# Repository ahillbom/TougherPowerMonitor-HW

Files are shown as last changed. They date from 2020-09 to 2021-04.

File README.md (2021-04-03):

### What is this?

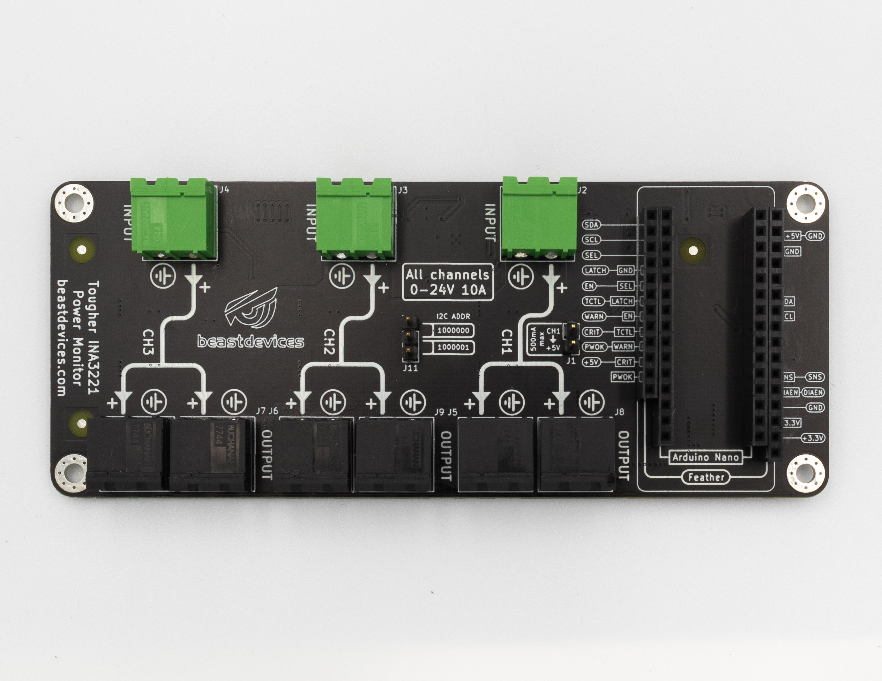
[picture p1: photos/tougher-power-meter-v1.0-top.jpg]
Tougher INA3221 power meter 3D side view. Assembled Tougher Power Meter Top View


Power monitor with three channels, each capable of continuous 10A and 24V. It is compatible with both Arduino and Feather, and is based on a popular INA3221. The power monitor is more robust compared to other modules based on this IC. Each channel has proper RC filtering with TVS diodes to prevent INA3221 from being destroyed by transients, and to eliminate glitches. Pluggable screw terminals are rated for 15A, and can handle 12 to 30 AWG wires.

The third channel has a TPS1HB08A power switch, to be able to disconnect the load.
The board can also provide power to the Feather or Arduino from the first channel via a built-in buck converter.

### Block diagram

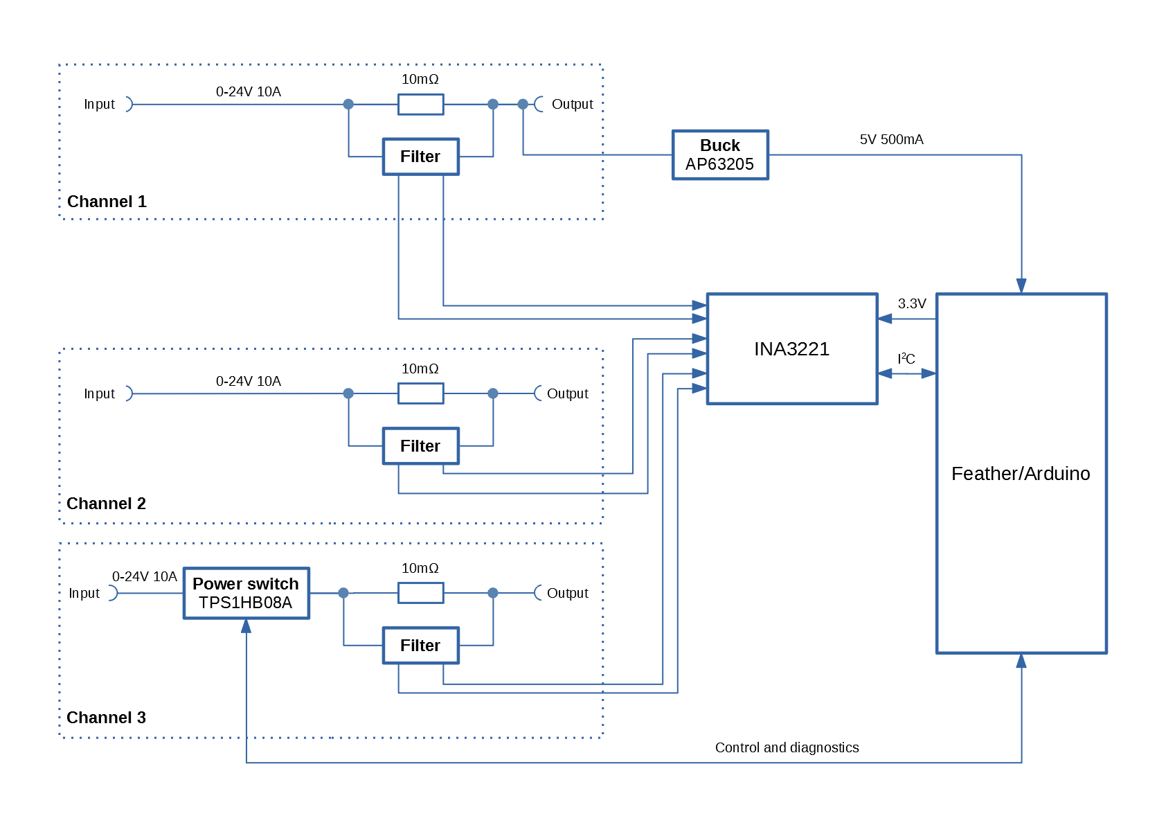
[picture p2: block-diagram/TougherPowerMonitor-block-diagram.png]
Tougher INA3221 Power Meter Block Diagram block diagram


### Schematics

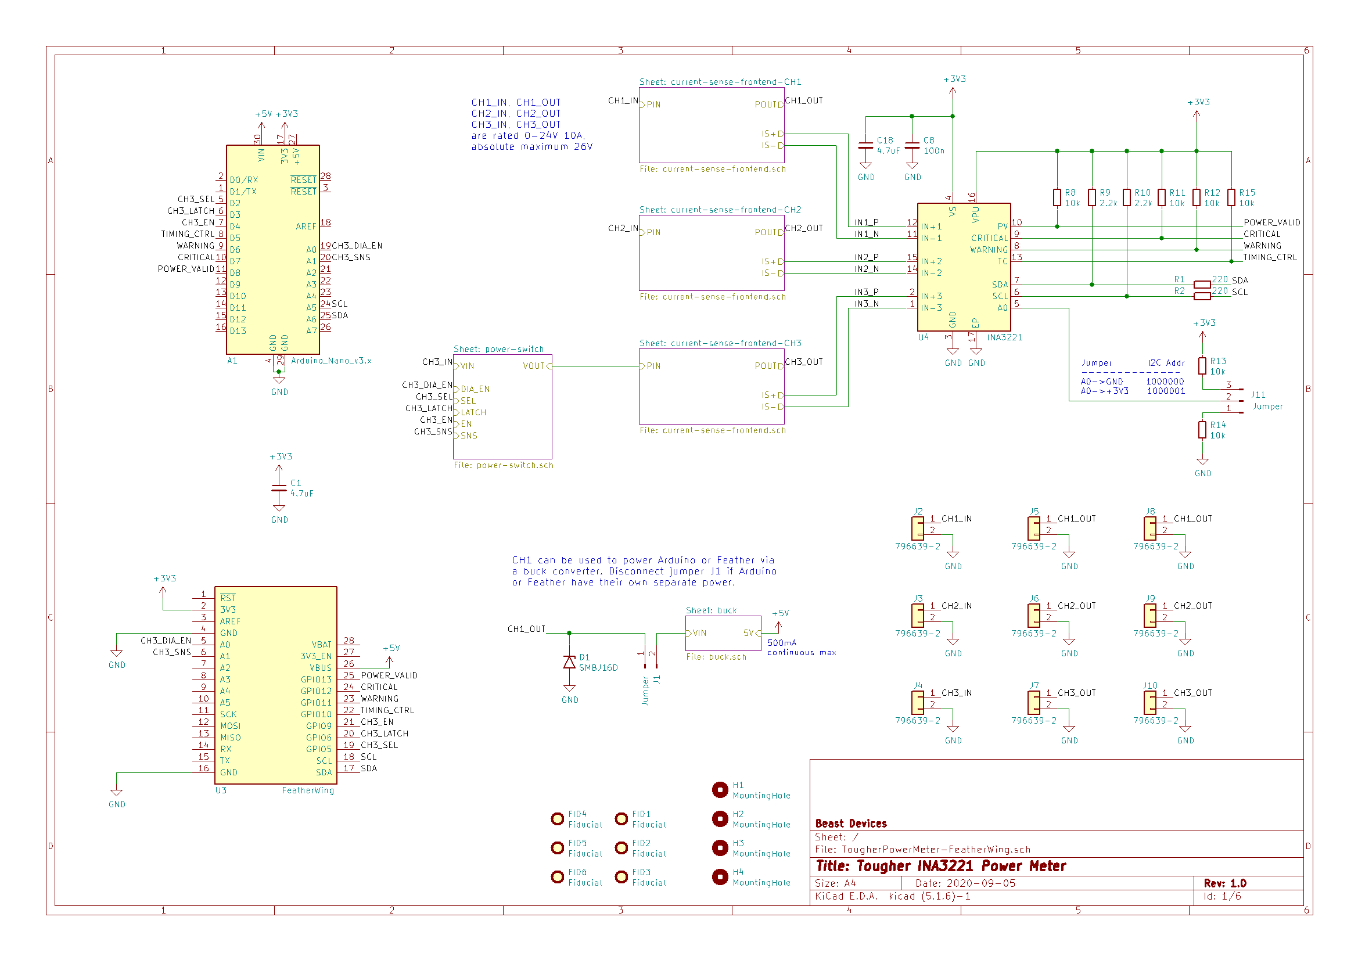
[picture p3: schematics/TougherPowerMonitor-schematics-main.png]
Tougher INA3221 Power Meter Schematics schematics


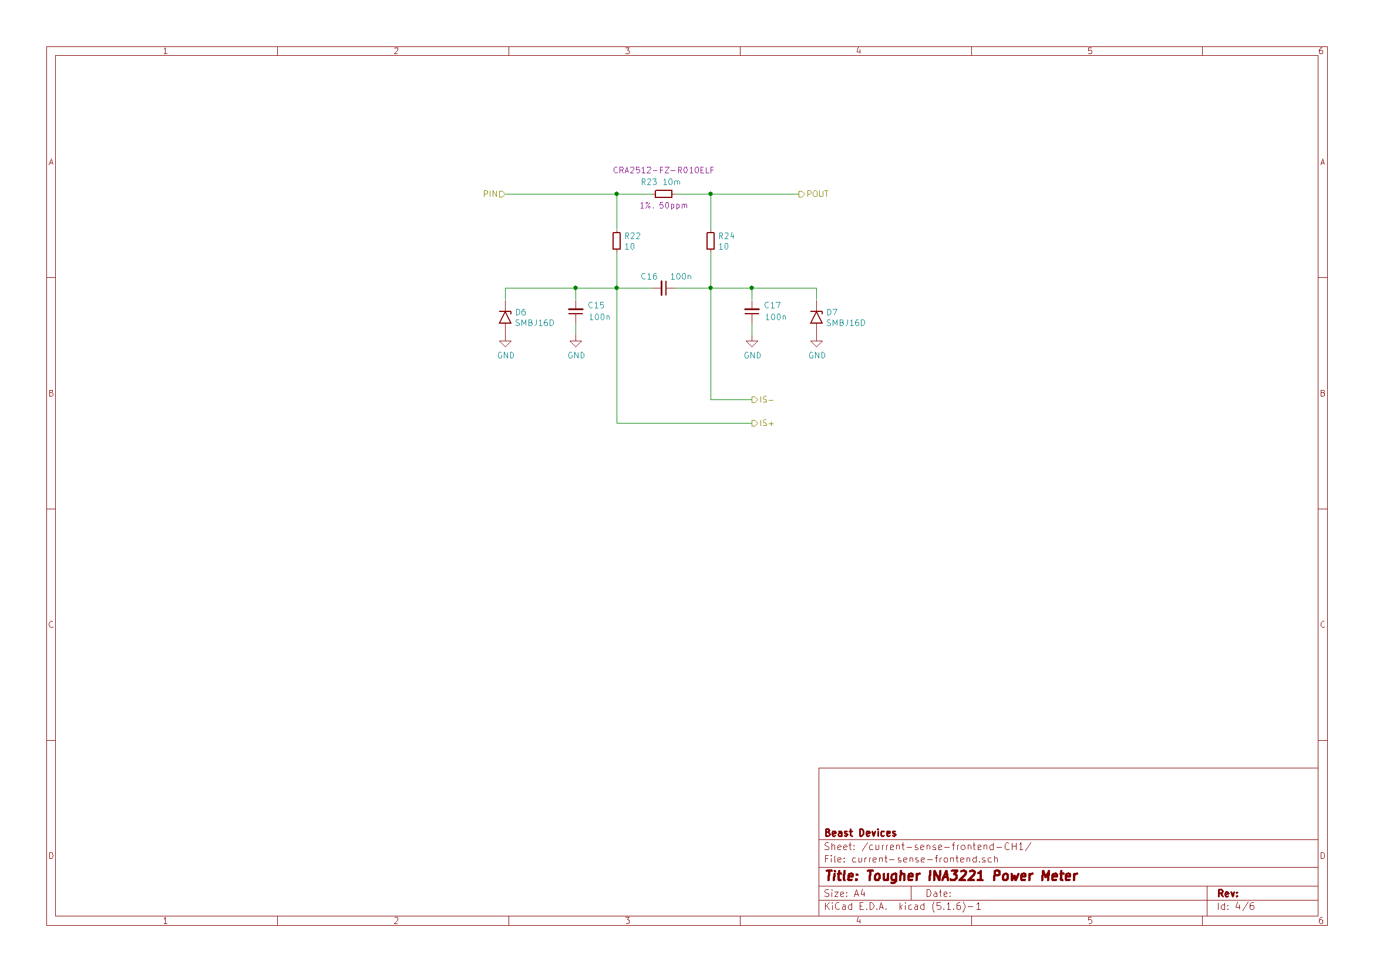
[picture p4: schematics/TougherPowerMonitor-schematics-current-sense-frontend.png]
Current sense resistor with RC filtering and TVS diodes. schematics


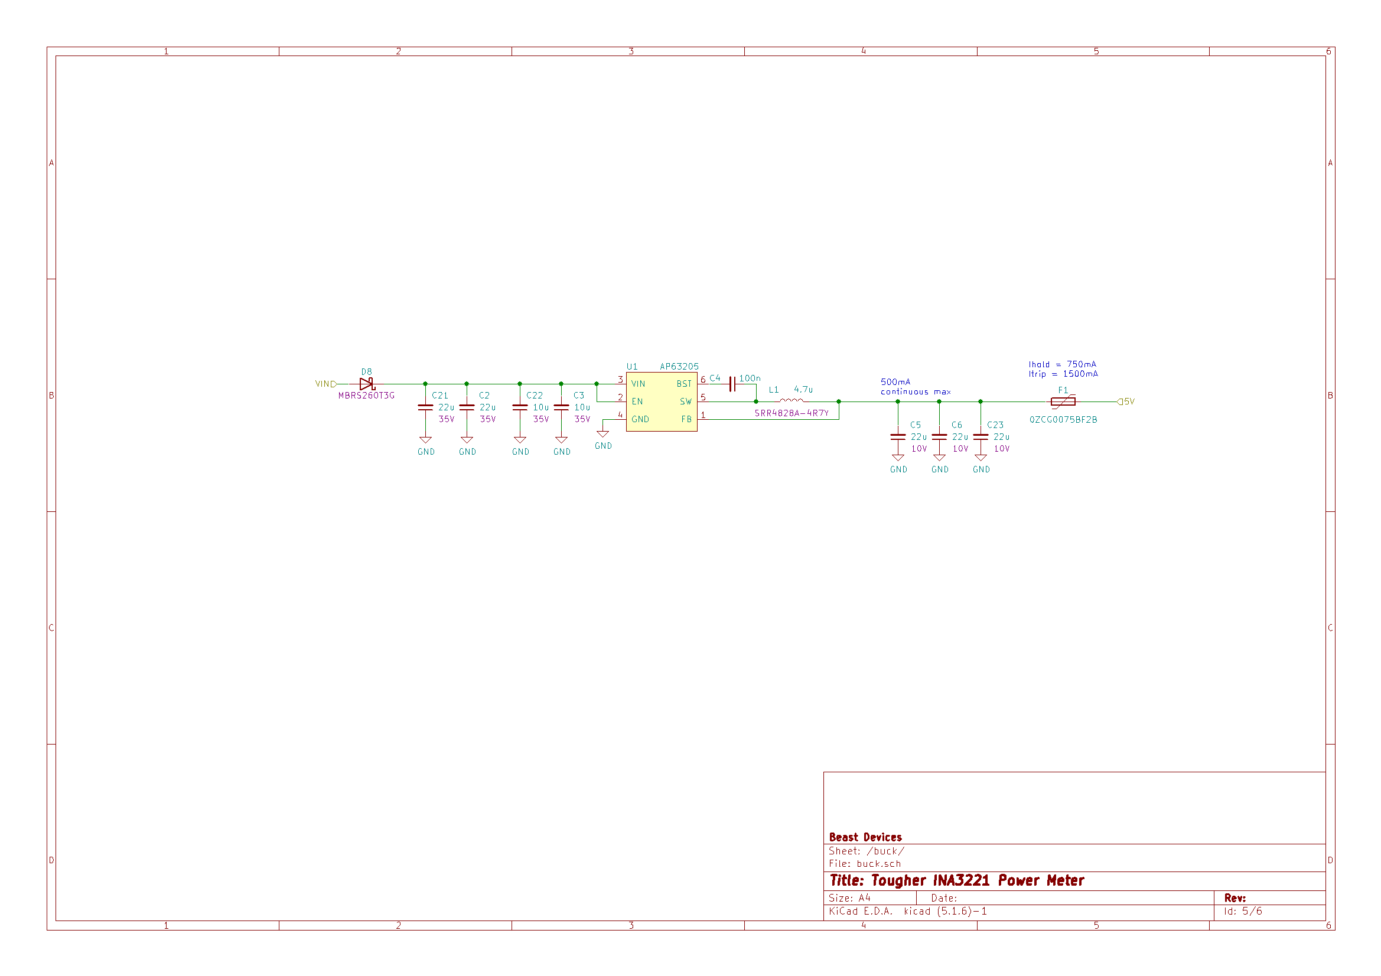
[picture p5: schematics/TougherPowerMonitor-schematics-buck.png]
Schematics of AP63205 buck converter. schematics


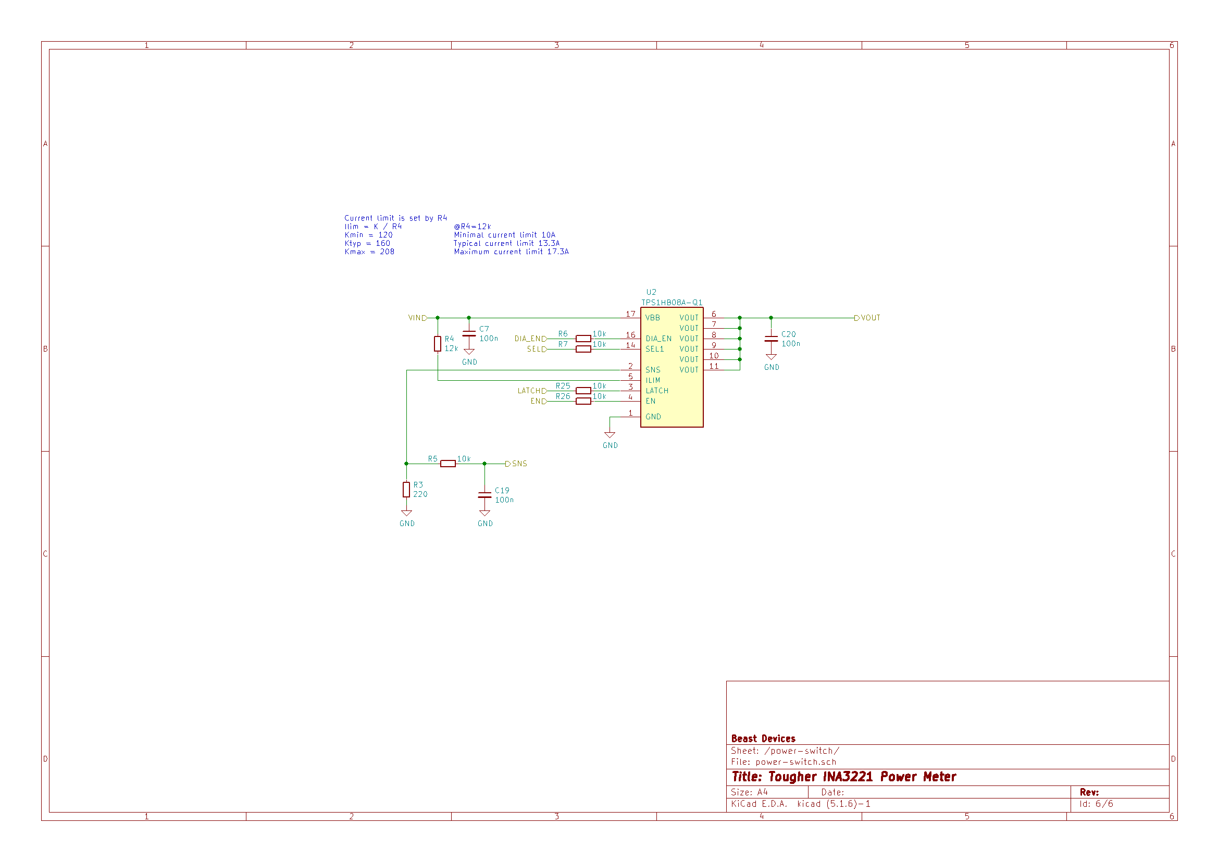
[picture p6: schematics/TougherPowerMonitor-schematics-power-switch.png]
Schematics of TPS1HB08 high-side power switch. schematics


### Assembled board

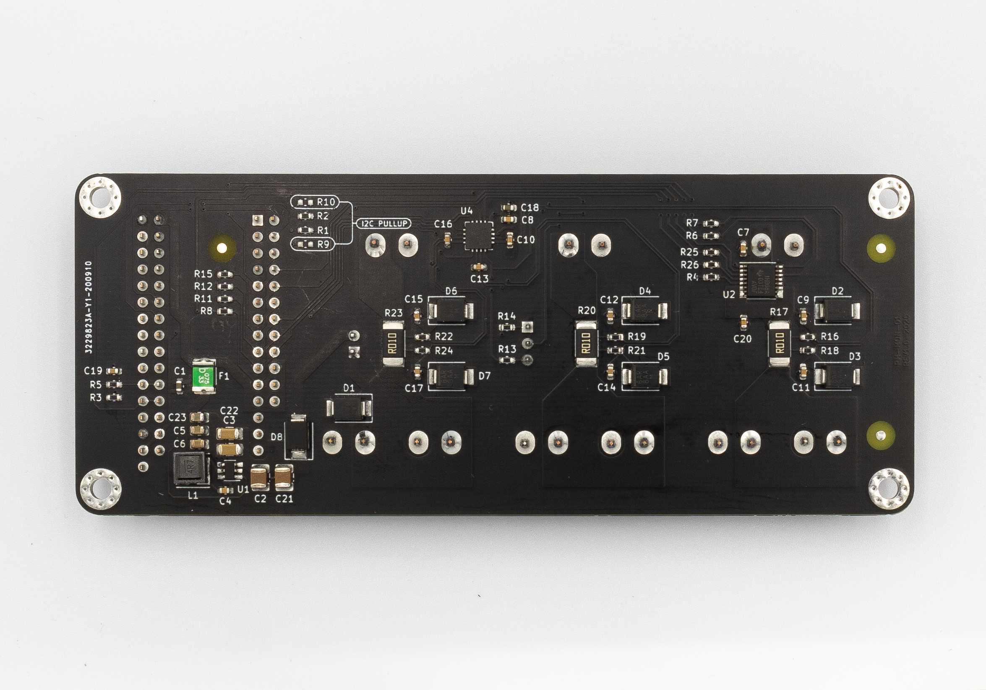
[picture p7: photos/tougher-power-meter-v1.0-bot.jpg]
Assebmbled Tougher Power Meter (bottom view). Assembled Tougher Power Meter Bottom View

Assebmbled Tougher Power Meter (side view). Assembled Tougher Power Meter Side View View

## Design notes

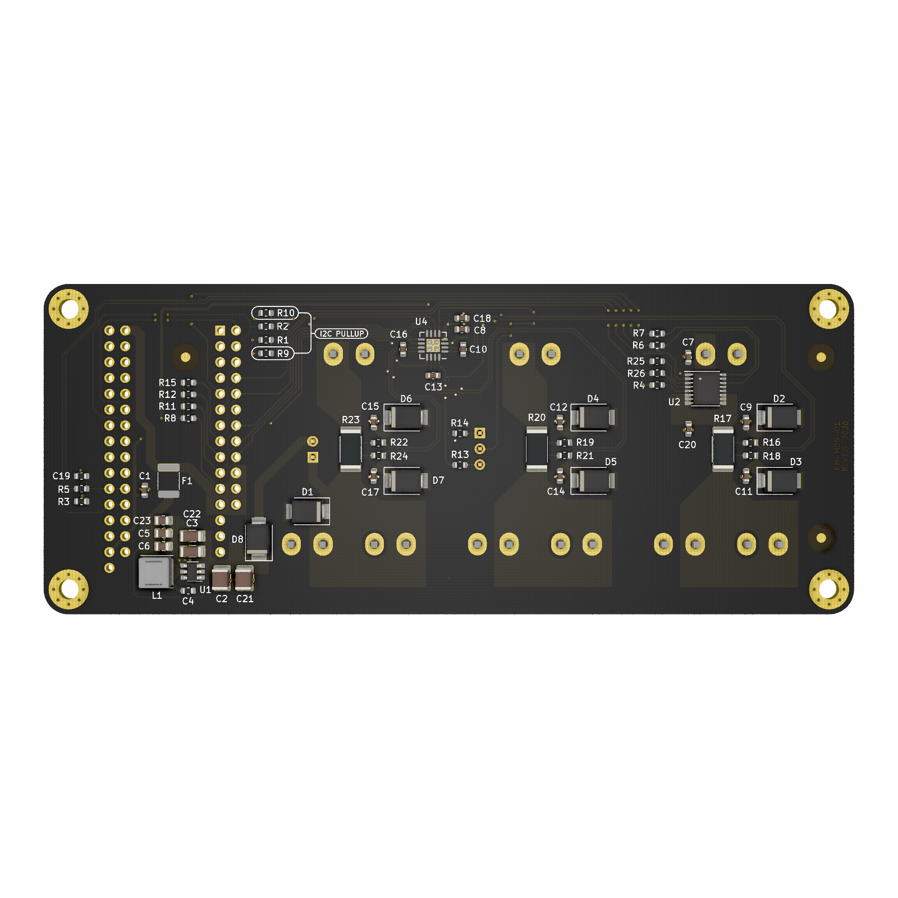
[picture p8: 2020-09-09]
3d-render/TougherPowerMeter-3D-Bottom.png

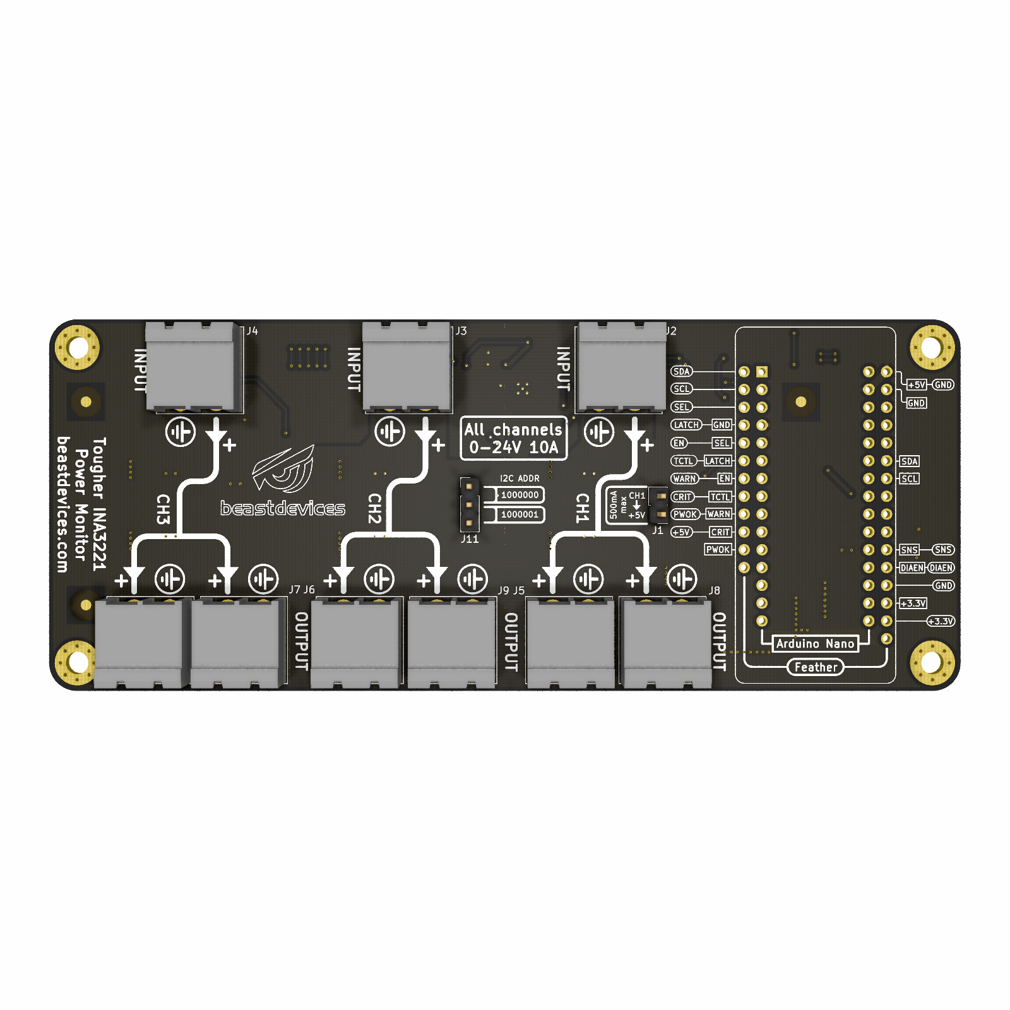
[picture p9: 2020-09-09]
3d-render/TougherPowerMeter-3D-Top.png

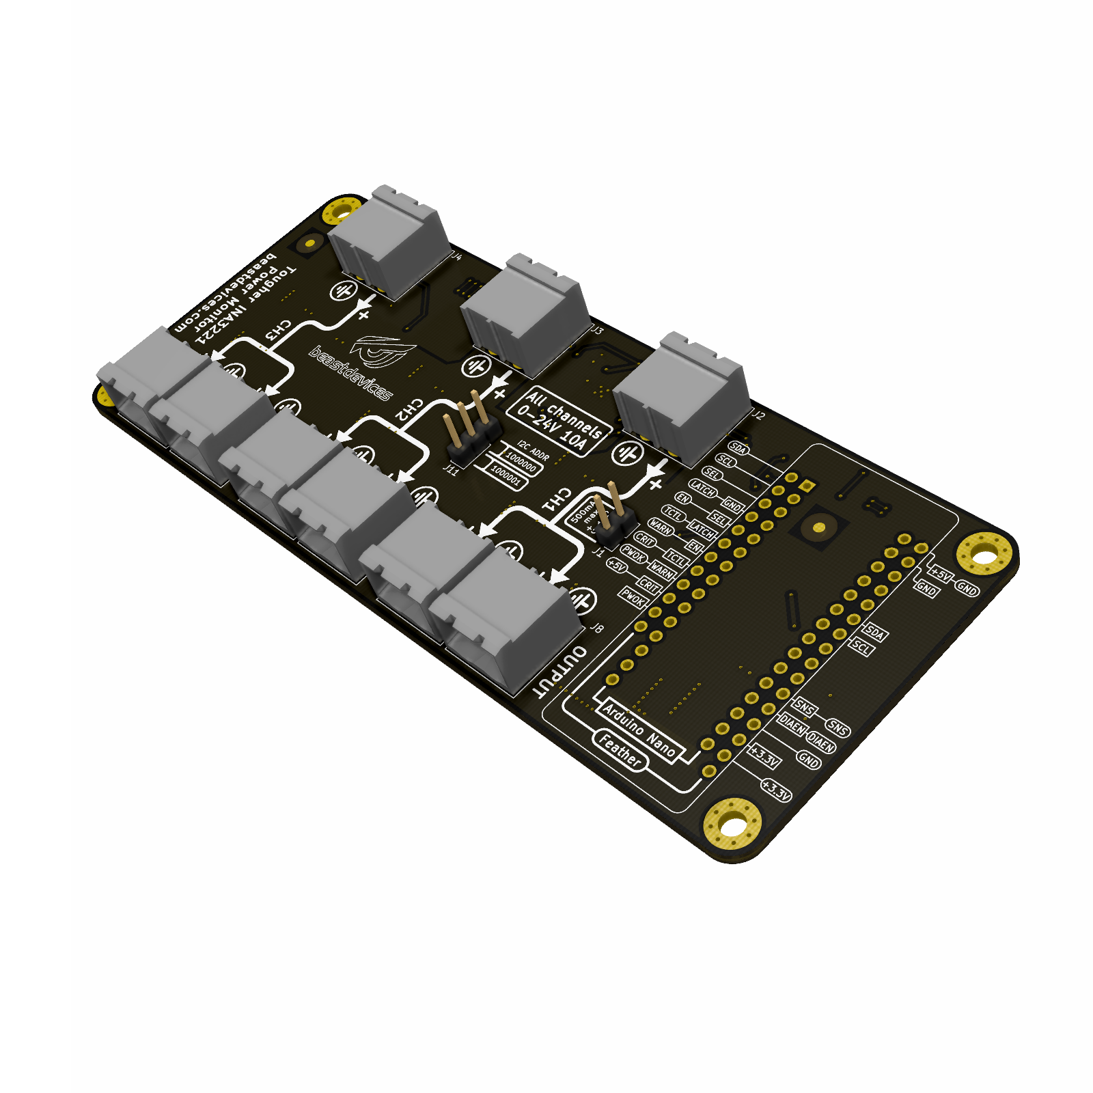
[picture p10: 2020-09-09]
3d-render/TougherPowerMeter-3D-Side.png

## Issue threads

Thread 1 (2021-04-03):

I2C SDA line is connected to wrong Arduino Nano pin

abondarevs, 2021-04-03:
The I2C SDA line is connected to the Arduino Nano pin A6, but should be connected to the pin A4.

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

7uc0, 2021-05-13:
Hi @abondarevs , as agreed I have checked out the master branch and would like to contribute and propose a PR for this issue, if you let my 7uc0 account contribute ( I will be the single Interface of my org to keep it simple) , I can proceed right away 8).

Thanks

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

7uc0, 2021-05-13:
Silk layer label position adjusted
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

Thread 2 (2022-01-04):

Question, pro/con of not just using the switch SENS with and ADC?

ptr727, 2022-01-04:
Given the switch has a sense output for current and temp monitoring, what are your thoughts on not just using e.g. multiple 2-channel TPS2HB08-Q1 and an onboard or I2C ADC?

abondarevs, 2022-01-04:
Your proposal is indeed a valid solution.

The main reason for not going in the direction you propose is not good enough current sense accuracy of the TPS2HB08-Q1.

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

ptr727, 2022-01-04:
I noticed from the accuracy graph on the notes that at low currents accuracy is very poor.
Yet, adding two load sense resistors is also not great.
I'm thinking one could choose the switch with sense and sacrifice accuracy, or use the sensor with a very low R switching FET?

I'm looking at a switching solution for a project like this: https://github.com/computergeek1507/PB_16/issues/2

abondarevs, 2022-07-16:
The primary purpose of this project is to measure the voltage and current with a reasonable accuracy. Typically, the current measurement using the FET resistance is good enough for ballpark measurements only. It is usually good enough for implementing current limiting, for example.

Closed 2024-04-26.

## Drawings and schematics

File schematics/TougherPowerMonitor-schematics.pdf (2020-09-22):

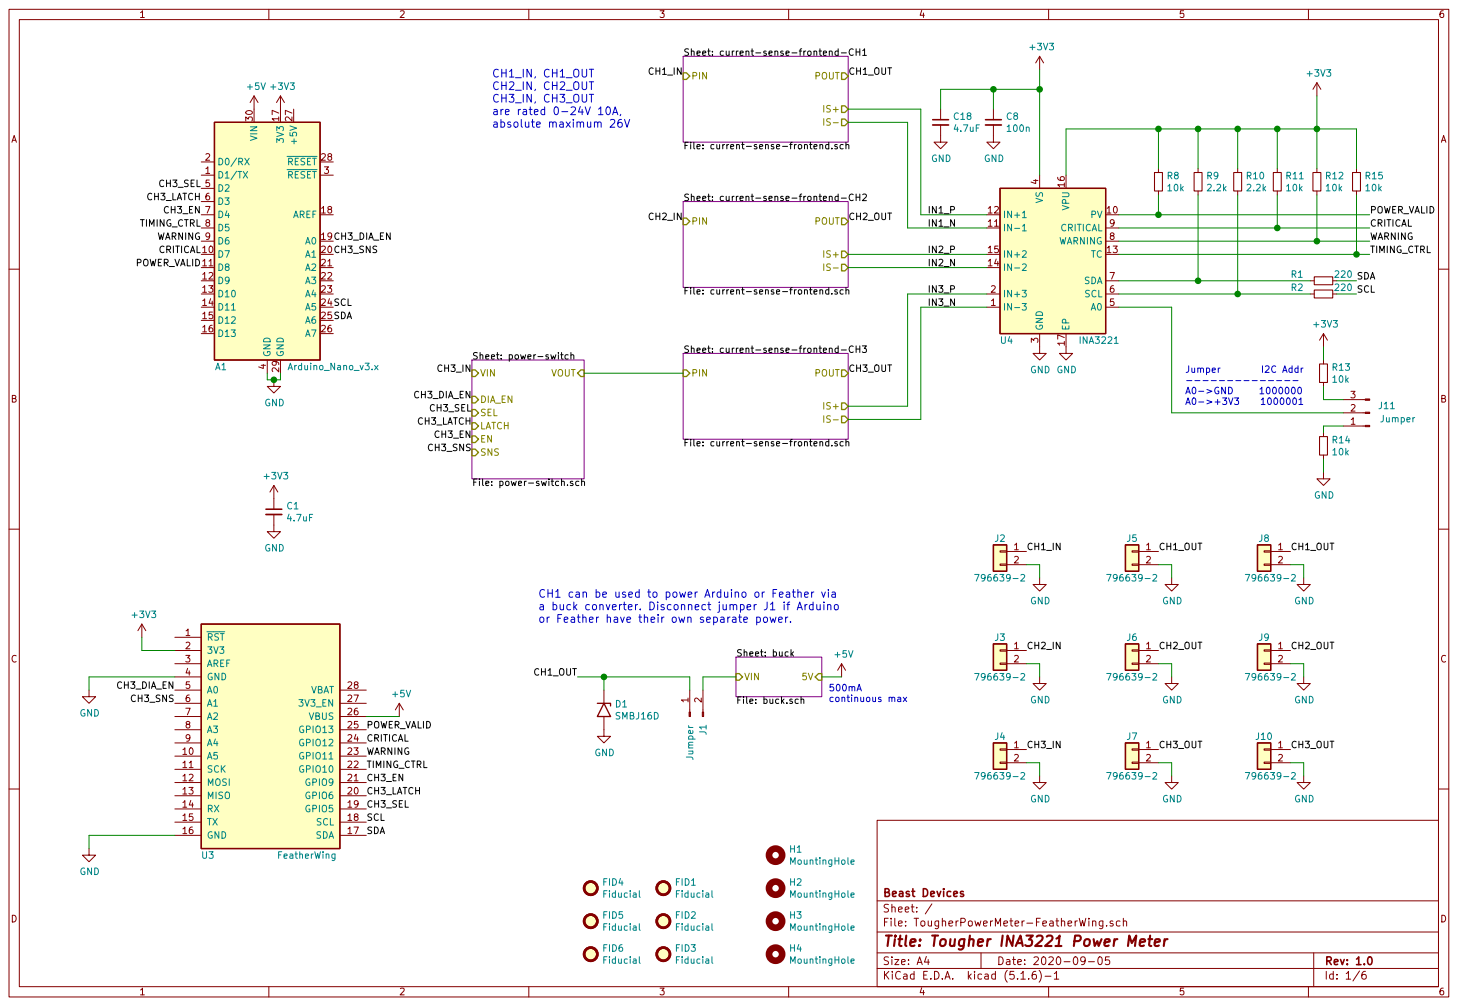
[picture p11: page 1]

4 A0 5 SCL 6 SDA 7 WARNING 8 CRITICAL 9 U4 INA3221 +3V3

IS+ Sheet: power-switch

a buck converter. Disconnect jumper J1 if Arduino
or Feather have their own separate power.

FID1 Fiducial FID2 Fiducial FID3 Fiducial FID4 Fiducial FID5 Fiducial FID6 Fiducial

File: TougherPowerMeter-FeatherWing.sch Sheet: / Beast Devices

Id: 1/6 Title: Tougher INA3221 Power Meter

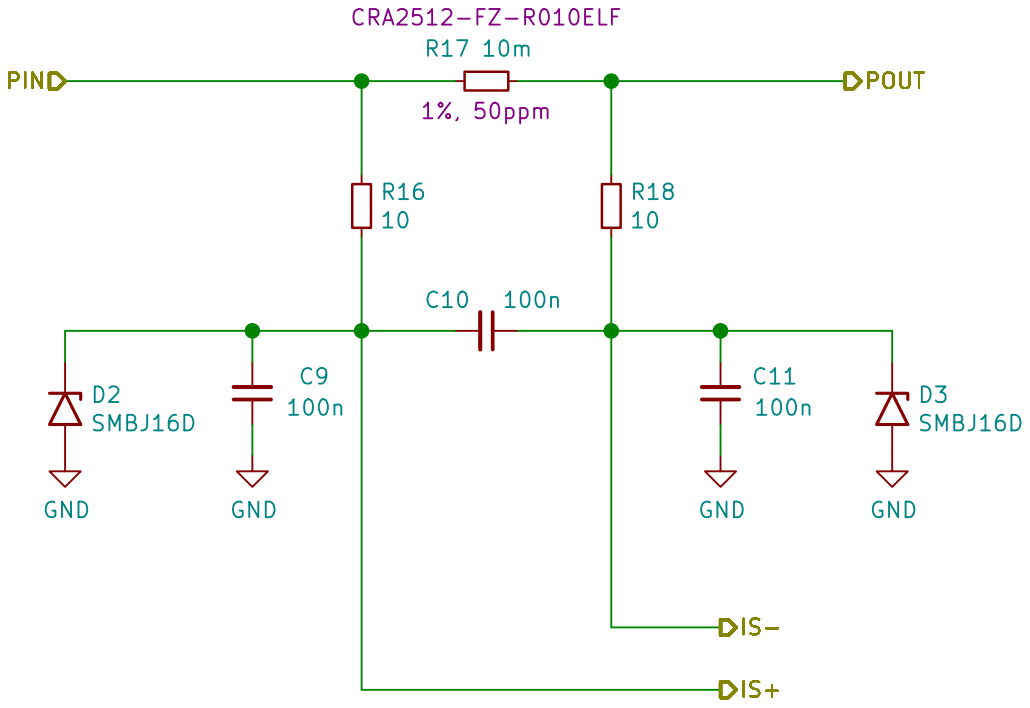
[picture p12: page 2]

Id: 2/6 Title: Tougher INA3221 Power Meter File: current-sense-frontend.sch Sheet: /current-sense-frontend-CH3/ Beast Devices

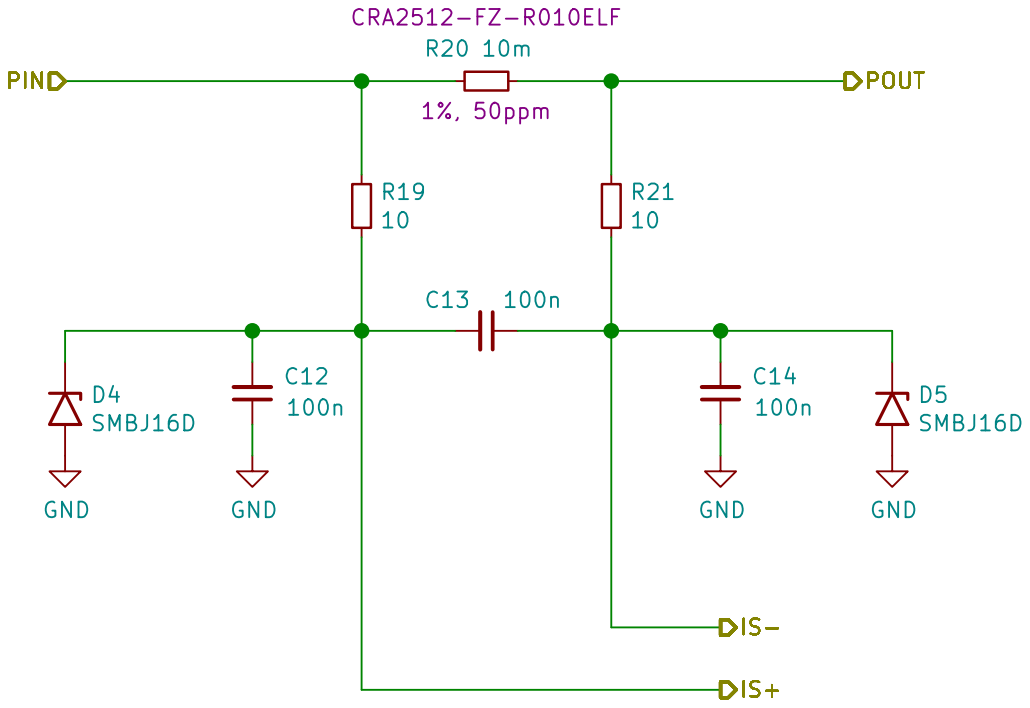
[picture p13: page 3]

Id: 3/6 Title: Tougher INA3221 Power Meter File: current-sense-frontend.sch Sheet: /current-sense-frontend-CH2/ Beast Devices

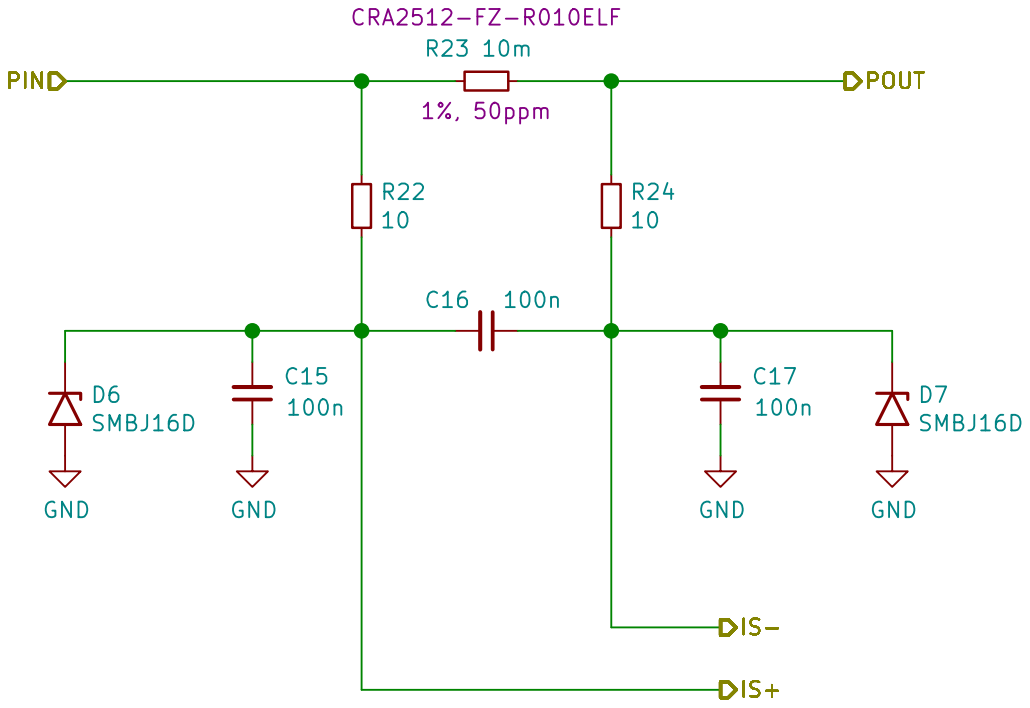
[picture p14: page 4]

Id: 4/6 Title: Tougher INA3221 Power Meter File: current-sense-frontend.sch Sheet: /current-sense-frontend-CH1/ Beast Devices

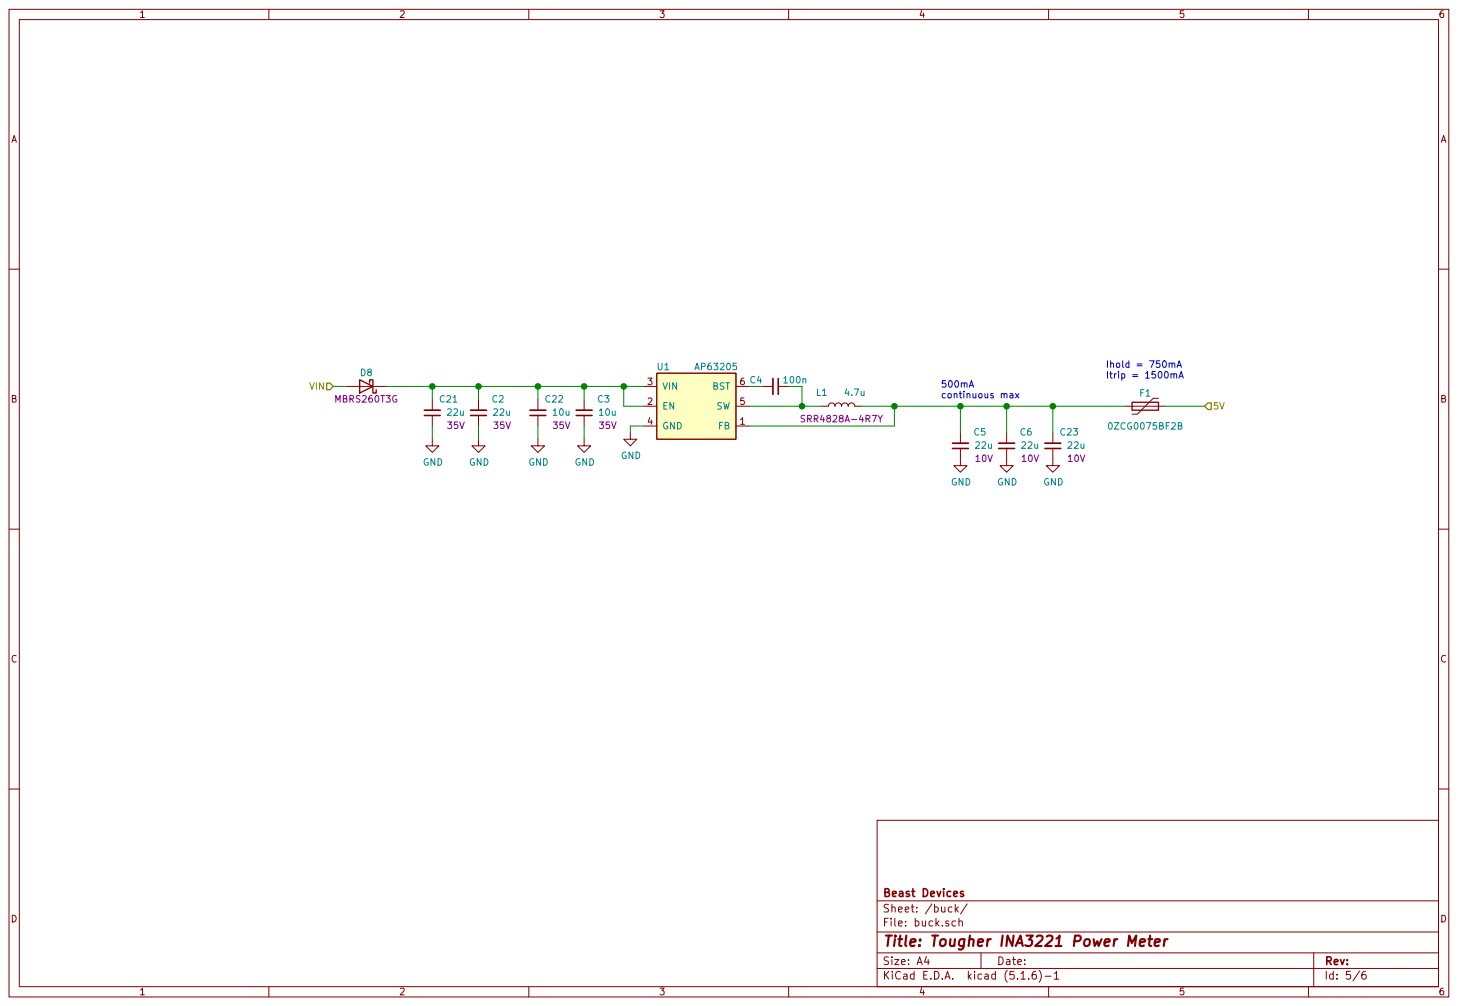
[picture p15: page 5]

Id: 5/6 Title: Tougher INA3221 Power Meter File: buck.sch Sheet: /buck/ Beast Devices

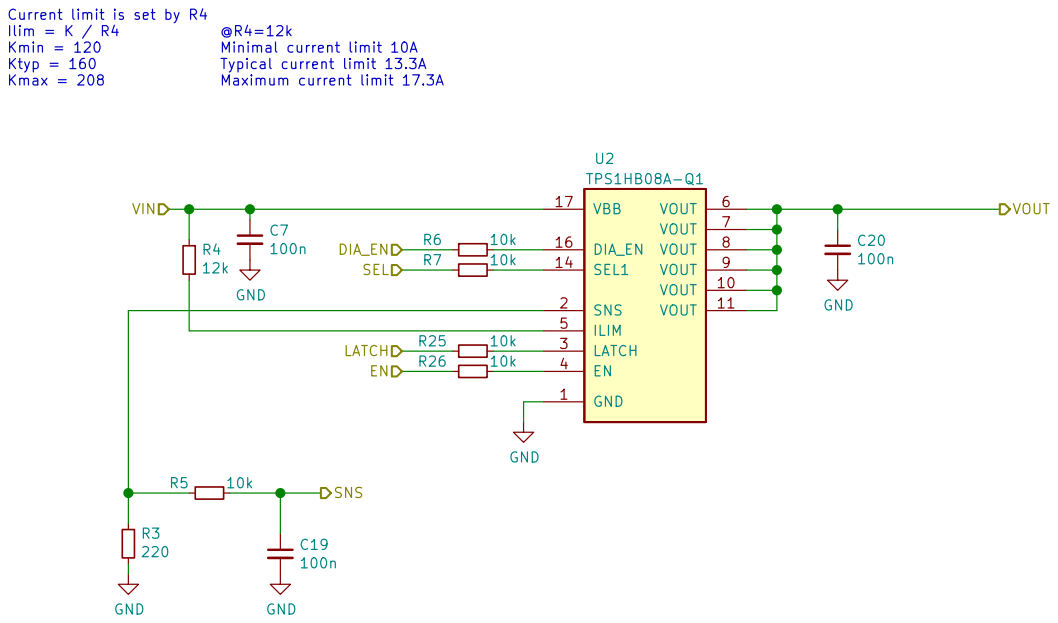
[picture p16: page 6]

Typical current limit 13.3A Maximum current limit 17.3A

File: power-switch.sch
Id: 6/6 Title: Tougher INA3221 Power Meter

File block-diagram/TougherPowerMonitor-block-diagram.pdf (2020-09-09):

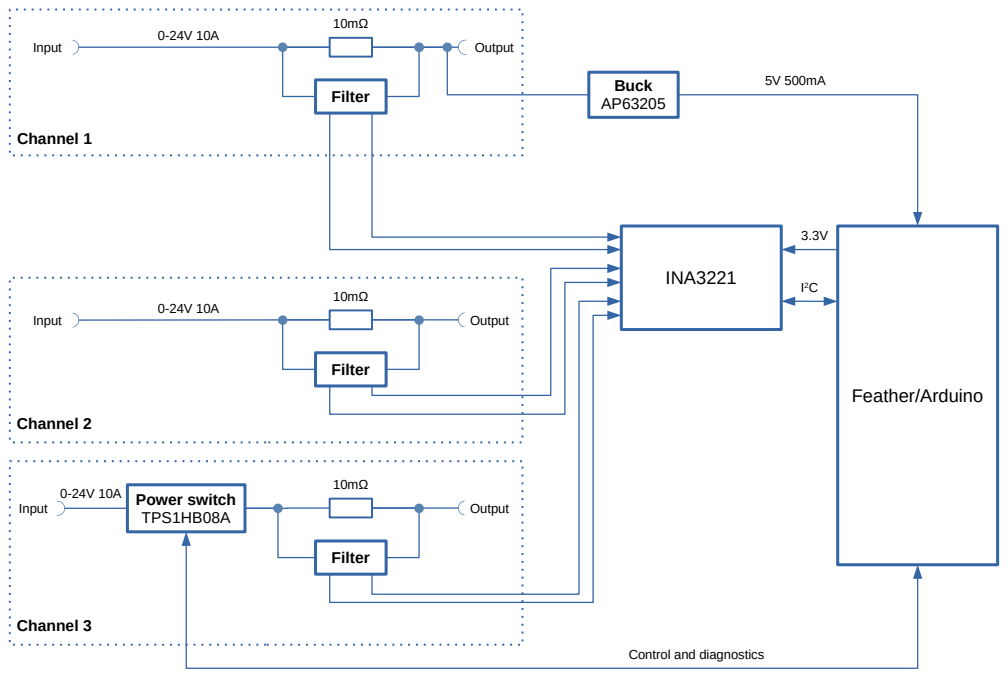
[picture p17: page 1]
INA3221; Filter; Channel 1; Buck AP63205; Feather/Arduino; Channel 2; Channel 3; Power switch TPS1HB08A; Input; Output

Control and diagnostics

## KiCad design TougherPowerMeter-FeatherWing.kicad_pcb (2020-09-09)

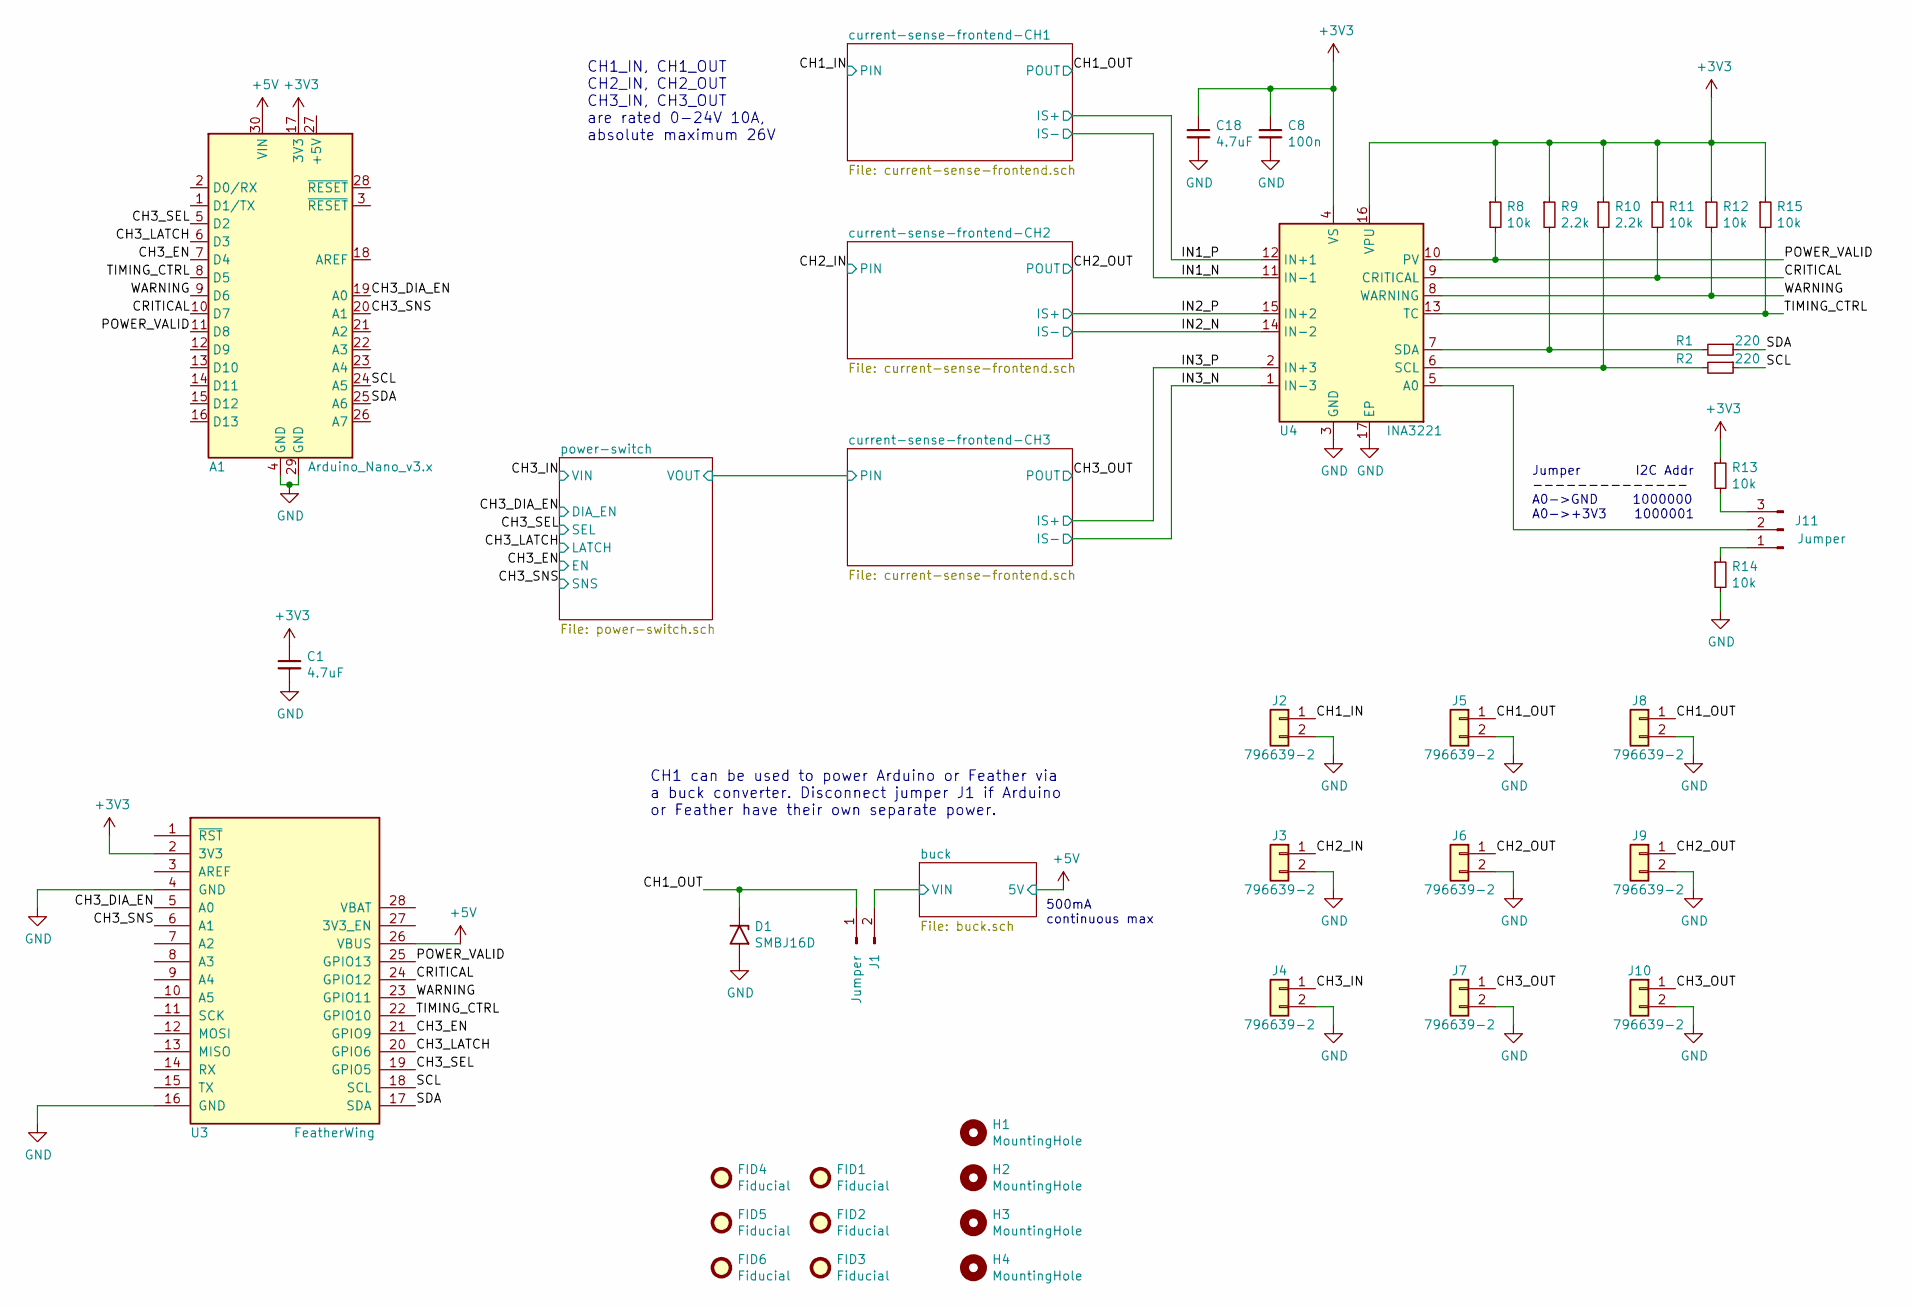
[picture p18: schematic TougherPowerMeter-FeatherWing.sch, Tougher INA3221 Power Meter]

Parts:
A1: Arduino_Nano_v3.x; Arduino_Nano_NoSilk
C1, C18: 4.7uF; C_0603_1608Metric
C8: 100n; C_0603_1608Metric
D1: SMBJ16D; D_SMB
FID1, FID2, FID3, FID4, FID5, FID6: Fiducial; Fiducial_1.5mm_Mask4.5mm
H1, H2, H3, H4: MountingHole; MountingHole_3.2mm_M3_Pad_Via
J1: Jumper; PinHeader_1x02_P2.54mm_Vertical
J2, J3, J4, J5, J6, J7, J8, J9, J10: 796639-2; TE_796639-2
J11: Jumper; PinHeader_1x03_P2.54mm_Vertical
R1, R2: 220; R_0603_1608Metric
R8, R11, R12, R13, R14, R15: 10k; R_0603_1608Metric
R9, R10: 2.2k; R_0603_1608Metric
U3: FeatherWing; FeatherWing_NoMH
U4: INA3221; Texas_RGV_S-PVQFN-N16_EP2.1x2.1mm

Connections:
+3V3: A1.17 (3V3), C1.1, C8.1, C18.1, R8.1, R9.1, R10.1, R11.1, R12.1, R13.1, R15.1, U3.2 (3V3), U4.4 (VS), U4.16 (VPU)
+5V: A1.30 (VIN), U3.26 (VBUS); also elsewhere on the board
/CH1_IN: J2.1; also elsewhere on the board
/CH1_OUT: D1.1 (A1), J1.1, J5.1, J8.1; also elsewhere on the board
/CH2_IN: J3.1; also elsewhere on the board
/CH2_OUT: J6.1, J9.1; also elsewhere on the board
/CH3_DIA_EN: A1.19 (A0), U3.5 (A0); also elsewhere on the board
/CH3_EN: A1.7 (D4), U3.21 (GPIO9); also elsewhere on the board
/CH3_IN: J4.1; also elsewhere on the board
/CH3_LATCH: A1.6 (D3), U3.20 (GPIO6); also elsewhere on the board
/CH3_OUT: J7.1, J10.1; also elsewhere on the board
/CH3_SEL: A1.5 (D2), U3.19 (GPIO5); also elsewhere on the board
/CH3_SNS: A1.20 (A1), U3.6 (A1); also elsewhere on the board
/CRITICAL: A1.10 (D7), R11.2, U3.24 (GPIO12), U4.9 (CRITICAL)
/IN1_N: U4.11 (IN-1); also elsewhere on the board
/IN1_P: U4.12 (IN+1); also elsewhere on the board
/IN2_N: U4.14 (IN-2); also elsewhere on the board
/IN2_P: U4.15 (IN+2); also elsewhere on the board
/IN3_N: U4.1 (IN-3); also elsewhere on the board
/IN3_P: U4.2 (IN+3); also elsewhere on the board
/POWER_VALID: A1.11 (D8), R8.2, U3.25 (GPIO13), U4.10 (PV)
/SCL: A1.24 (A5), R2.1, U3.18 (SCL)
/SDA: A1.25 (A6), R1.1, U3.17 (SDA)
/TIMING_CTRL: A1.8 (D5), R15.2, U3.22 (GPIO10), U4.13 (TC)
/WARNING: A1.9 (D6), R12.2, U3.23 (GPIO11), U4.8 (WARNING)
/buck/VIN: J1.2; also elsewhere on the board
GND: A1.4 (GND), A1.29 (GND), C1.2, C8.2, C18.2, D1.2 (A2), J2.2, J3.2, J4.2, J5.2, J6.2, J7.2, J8.2, J9.2, J10.2, R14.2, U3.4 (GND), U3.16 (GND), U4.3 (GND), U4.17 (EP); also elsewhere on the board
unnamed: J11.1, R14.1
unnamed: J11.2, U4.5 (A0)
unnamed: J11.3, R13.2
unnamed: R1.2, R9.2, U4.7 (SDA)
unnamed: R2.2, R10.2, U4.6 (SCL)

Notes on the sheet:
Jumper I2C Addr -------------- A0->GND 1000000 A0->+3V3 1000001
CH1_IN, CH1_OUT CH2_IN, CH2_OUT CH3_IN, CH3_OUT are rated 0-24V 10A, absolute maximum 26V
CH1 can be used to power Arduino or Feather via a buck converter. Disconnect jumper J1 if Arduino or Feather have their own separate power.
500mA continuous max

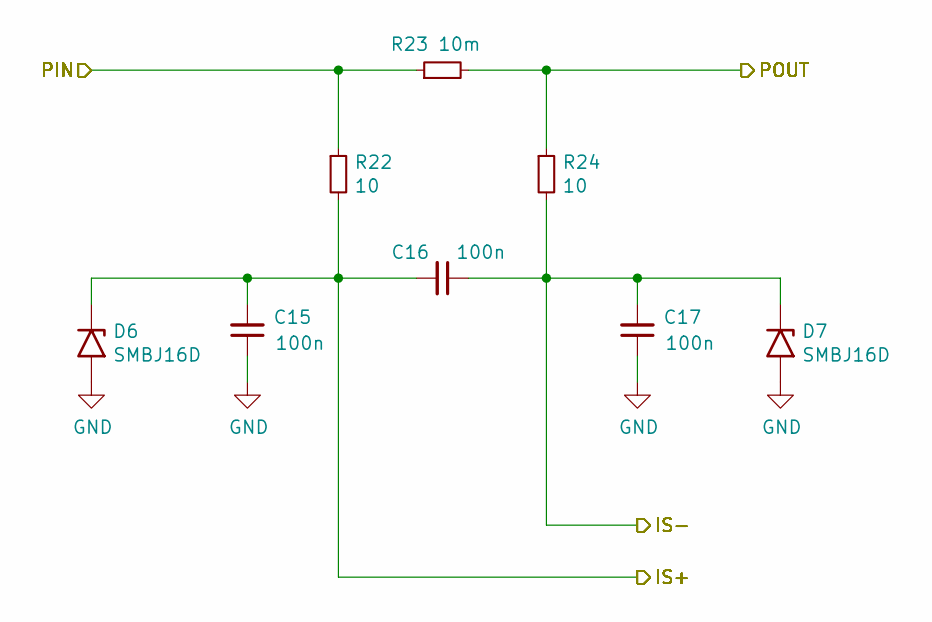
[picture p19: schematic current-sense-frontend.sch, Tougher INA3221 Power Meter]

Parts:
C9, C10, C11: 100n; C_0603_1608Metric
D2, D3: SMBJ16D; D_SMB
R16, R18: 10; R_0603_1608Metric
R17: 10m; R_2512_6332Metric

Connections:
/CH3_OUT: R17.2, R18.1; also elsewhere on the board
/IN3_N: C10.1, C11.2, D3.1 (A1), R18.2; also elsewhere on the board
/IN3_P: C9.2, C10.2, D2.1 (A1), R16.2; also elsewhere on the board
/current-sense-frontend-CH3/PIN: R16.1, R17.1; also elsewhere on the board
GND: C9.1, C11.1, D2.2 (A2), D3.2 (A2); also elsewhere on the board

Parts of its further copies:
C12, C13, C14, C15, C16, C17: 100n; C_0603_1608Metric
D4, D5, D6, D7: SMBJ16D; D_SMB
R19, R21, R22, R24: 10; R_0603_1608Metric
R20, R23: 10m; R_2512_6332Metric

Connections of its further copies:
/CH1_IN: R22.1, R23.1; also elsewhere on the board
/CH1_OUT: R23.2, R24.1; also elsewhere on the board
/CH2_IN: R19.1, R20.1; also elsewhere on the board
/CH2_OUT: R20.2, R21.1; also elsewhere on the board
/IN1_N: C16.1, C17.2, D7.1 (A1), R24.2; also elsewhere on the board
/IN1_P: C15.2, C16.2, D6.1 (A1), R22.2; also elsewhere on the board
/IN2_N: C13.1, C14.2, D5.1 (A1), R21.2; also elsewhere on the board
/IN2_P: C12.2, C13.2, D4.1 (A1), R19.2; also elsewhere on the board
GND: C12.1, C14.1, C15.1, C17.1, D4.2 (A2), D5.2 (A2), D6.2 (A2), D7.2 (A2); also elsewhere on the board

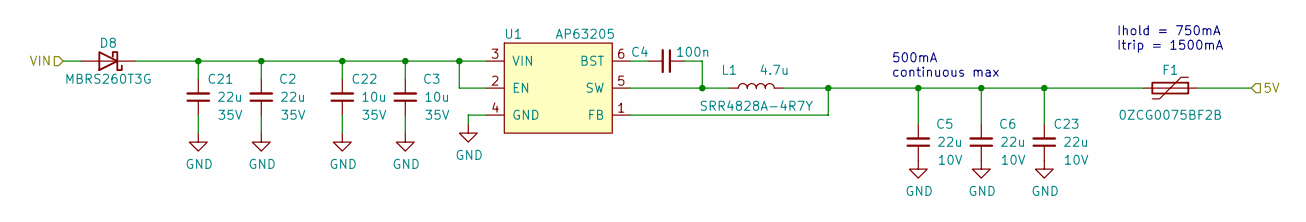
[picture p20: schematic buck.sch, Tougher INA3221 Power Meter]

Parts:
C2, C21: 22u; C_1210_3225Metric; Voltage 35V
C3, C22: 10u; C_1206_3216Metric; Voltage 35V
C4: 100n; R_0603_1608Metric
C5, C6, C23: 22u; C_0805_2012Metric; Voltage 10V
D8: D_Schottky; D_SMB; Part Number MBRS260T3G
F1: 0ZCG0075BF2B; Fuse_1812_4532Metric; Part Number 0ZCG0075BF2B
L1: 4.7u; L_Bourns_SRR1210A; Part Number SRR4828A-4R7Y
U1: AP63205; TSOT-23-6

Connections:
+5V: F1.1; also elsewhere on the board
/buck/VIN: D8.2 (A); also elsewhere on the board
GND: C2.1, C3.1, C5.1, C6.1, C21.1, C22.1, C23.1, U1.4 (GND); also elsewhere on the board
unnamed: C2.2, C3.2, C21.2, C22.2, D8.1 (K), U1.2 (EN), U1.3 (VIN)
unnamed: C4.1, L1.1, U1.5 (SW)
unnamed: C4.2, U1.6 (BST)
unnamed: C5.2, C6.2, C23.2, F1.2, L1.2, U1.1 (FB)

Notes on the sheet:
500mA continuous max
Ihold = 750mA Itrip = 1500mA

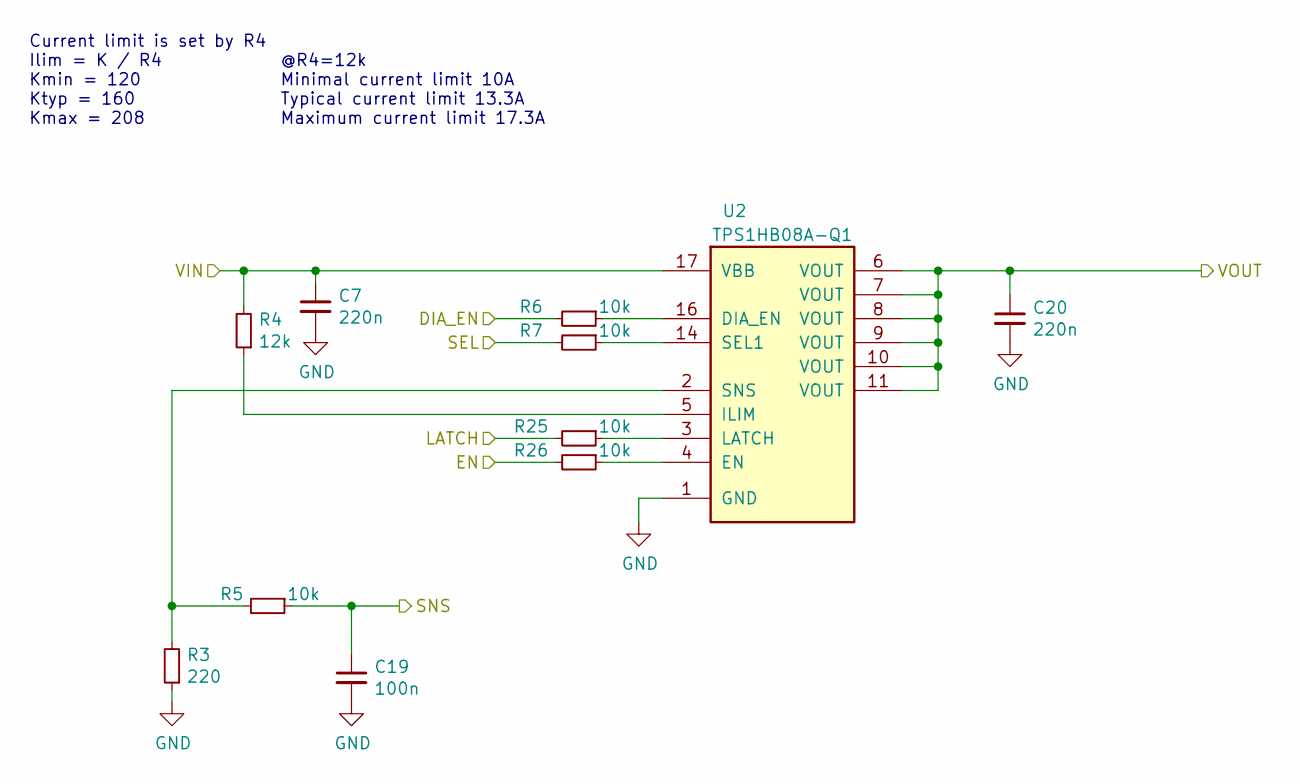
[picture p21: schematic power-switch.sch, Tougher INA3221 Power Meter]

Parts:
C7, C20: 220n; C_0603_1608Metric
C19: 100n; R_0603_1608Metric
R3: 220; R_0603_1608Metric
R4: 12k; R_0603_1608Metric
R5, R6, R7, R25, R26: 10k; R_0603_1608Metric
U2: TPS1HB08A-Q1; HTSSOP-16-1EP_4.4x5mm_P0.65mm_EP3.4x5mm

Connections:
/CH3_DIA_EN: R6.2; also elsewhere on the board
/CH3_EN: R26.2; also elsewhere on the board
/CH3_IN: C7.1, R4.2, U2.17 (VBB); also elsewhere on the board
/CH3_LATCH: R25.2; also elsewhere on the board
/CH3_SEL: R7.2; also elsewhere on the board
/CH3_SNS: C19.1, R5.1; also elsewhere on the board
/current-sense-frontend-CH3/PIN: C20.1, U2.6 (VOUT), U2.7 (VOUT), U2.8 (VOUT), U2.9 (VOUT), U2.10 (VOUT), U2.11 (VOUT); also elsewhere on the board
GND: C7.2, C19.2, C20.2, R3.1, U2.1 (GND); also elsewhere on the board
unnamed: R3.2, R5.2, U2.2 (SNS)
unnamed: R4.1, U2.5 (ILIM)
unnamed: R6.1, U2.16 (DIA_EN)
unnamed: R7.1, U2.14 (SEL1)
unnamed: R25.1, U2.3 (LATCH)
unnamed: R26.1, U2.4 (EN)

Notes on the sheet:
Current limit is set by R4 Ilim = K / R4 Kmin = 120 Ktyp = 160 Kmax = 208
@R4=12k Minimal current limit 10A Typical current limit 13.3A Maximum current limit 17.3A

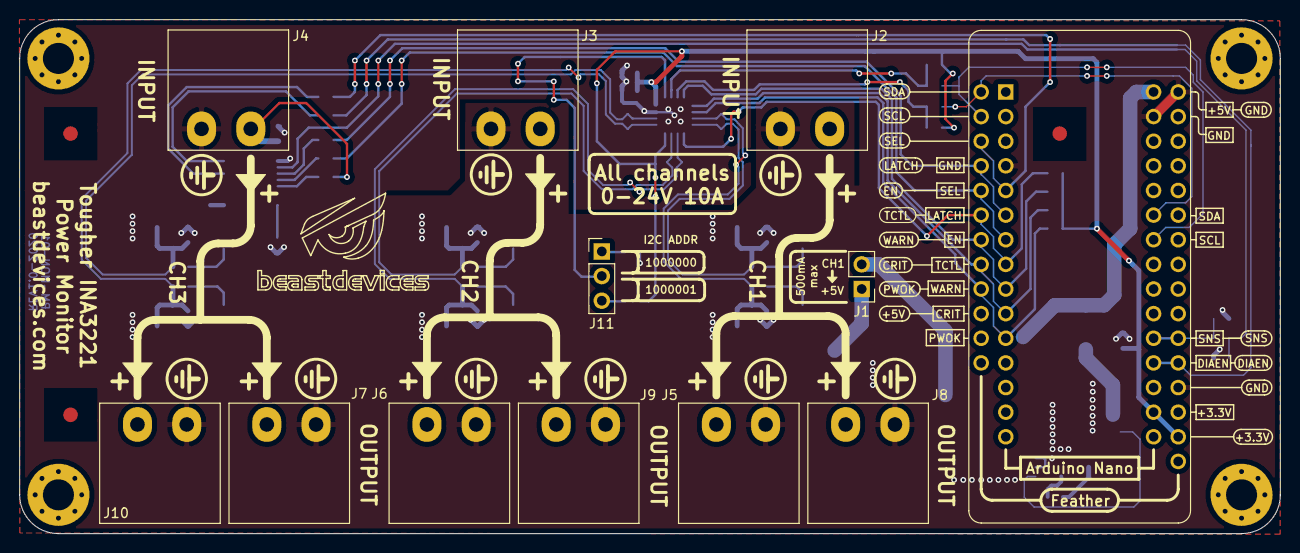
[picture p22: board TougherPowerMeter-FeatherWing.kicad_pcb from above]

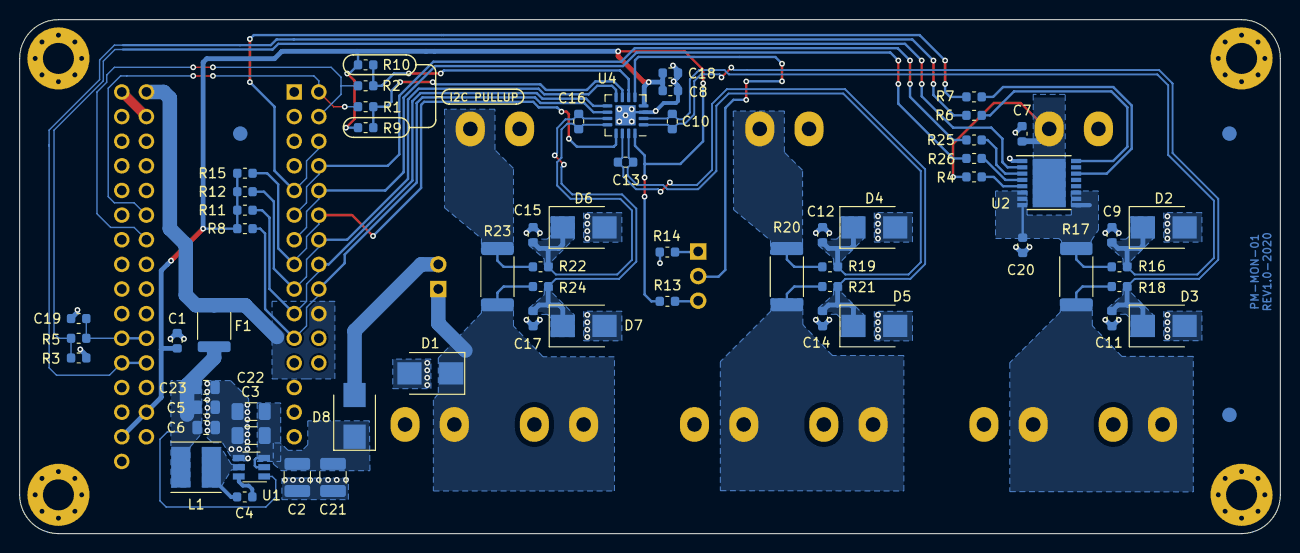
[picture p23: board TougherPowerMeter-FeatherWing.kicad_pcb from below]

Board: 2 copper layers, 130.0 x 53.0 mm, 85 parts (65 on the bottom side), 43 nets.

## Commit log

2020-09-05 Finish design
    [TougherPowerMeter-FeatherWing.kicad_pcb, TougherPowerMeter-FeatherWing.sch, buck.sch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]
2020-09-05 Add fiducials, fix aesthetics in schematics
    [TougherPowerMeter-FeatherWing.kicad_pcb, TougherPowerMeter-FeatherWing.sch, buck.sch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]
2020-09-05 Add schematics PDF and 3D renderings of PBA
2020-09-05 Add comment to schematics:
    CH1 can be used to power Arduino or Feather via
    a buck converter. Disconnect jumper J1 if Arduino
    or Feather have their own separate power.
    [TougherPowerMeter-FeatherWing.sch]
2020-09-09 Add 3D renderings and update exported schematics
    [TougherPowerMeter-FeatherWing.kicad_pcb]
2020-09-09 Generate Gerber files (rev1.0-2020)
    [TougherPowerMeter-FeatherWing-B_Cu.gbr, TougherPowerMeter-FeatherWing-B_Mask.gbr, TougherPowerMeter-FeatherWing-B_Paste.gbr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]
2020-09-14 Add manufacturers, part numbers, and supplier links
    [TougherPowerMeter-FeatherWing.sch, buck.sch, current-sense-frontend.sch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]
2020-09-22 Change part number for the current sense resistor
    [current-sense-frontend.sch]
2020-09-22 Update schematics exports
2021-04-03 Add photos of assembled PBA v1.0
2021-05-13 Add submodule for the KiCad libraries.
    Add submodule for the KiCad libraries and change
    references to the libraries.
    [TougherPowerMeter-FeatherWing.sch, current-sense-frontend.sch]
